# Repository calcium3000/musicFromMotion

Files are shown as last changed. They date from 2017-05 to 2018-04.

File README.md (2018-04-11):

# musicFromMotion
Convert your slick grooves into sweet tunes.  Body movements are transmitted wirelessly to a host computer and then translated into pre-programmed beats and instruments.  And everything is reconfigurable on the fly; you can serenade or offend the airwaves however you please.

See https://calcium3000.wordpress.com/projects/mfm for more information on the project.

## Hardware
### mFM-Rx
This is the receiver module with which all transmitter nodes communicate.  It consists of a small breakout board for a mini nRF24L01+ transceiver module that plugs directly into the SPI0 bus of a Raspberry Pi (all models).

This module is used in conjunction with TMRh20's RF24 library (see https://github.com/TMRh20/RF24).

### mFM-Tx
Behold the transmitter modules -- the lustrous face of mFM.  Each module consists of a battery, a voltage regulator, a radio transceiver, an accelerometer, and a microcontroller.

When the Rx node pings a Tx node, it reads it accelerometer value and battery status (good or low), sends it back to the Rx node, and takes a quick nap while the other nodes are being pinged.  If the battery voltage is too low the module will sleep until the battery is recharged.

**Note: this version is currently in progress and untested.  Use at your own risk!  And if you do and have any comments or suggestions, please share!**

### License
mFM hardware is licensed under the TAPR Open Hardware License.  See http://tapr.org/ohl.html or LICENSE.txt for full details of the license agreement.

## Software
This section is currently under construction -- i.e. I need to get everything pretty enough to share on the interwebs.  But behold the list of eventual components:
- Tx firmware (Arduino)
- Rx program (C++)
- Rx UDP configurator GUI (optional, Python)
- Main audio program (Pure Data)

### License
All software is licensed under the GNU Public License (GPL) version 3.  See https://www.gnu.org/licenses or COPYING.txt for full details of the license agreement.

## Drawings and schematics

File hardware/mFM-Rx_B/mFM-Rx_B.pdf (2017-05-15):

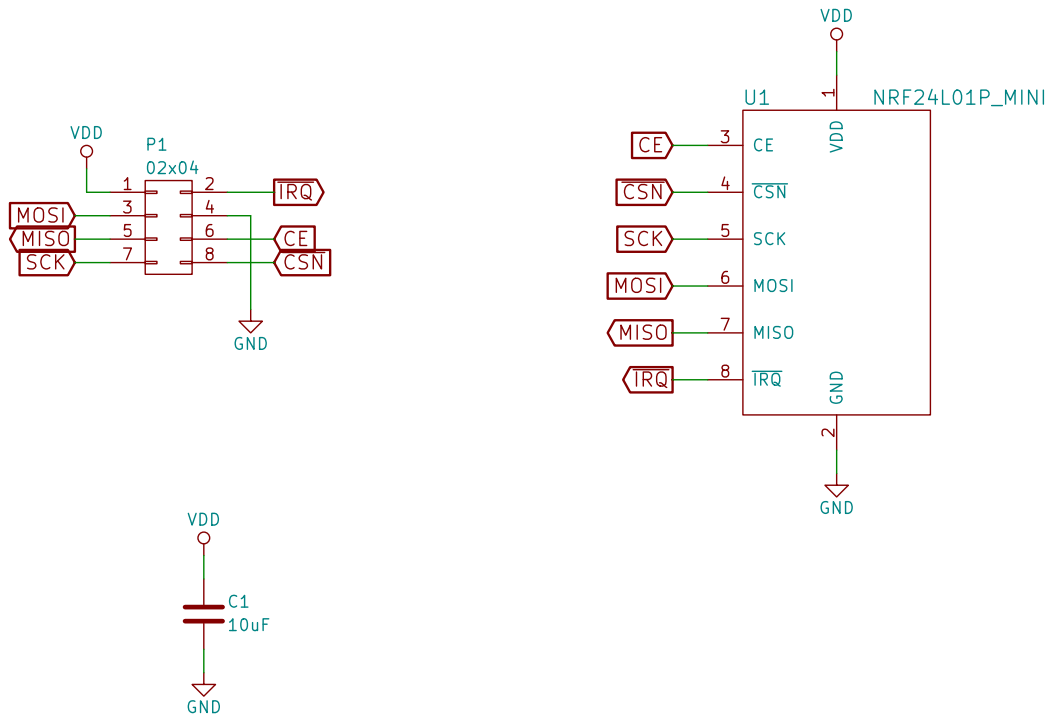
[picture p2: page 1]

1 GND
Released under the TAPR Open Hardware License >> http://tapr.org/ohl.html VDD

2 CE 3 CSN 4 SCK 5 MOSI 6 MISO 7

File: mFM-Rx_B.sch Sheet: / By Calvin A. Cherry >> calvincherry@gmail.com

Id: 1/1 Title: musicFromMotion Receiver (Rx)

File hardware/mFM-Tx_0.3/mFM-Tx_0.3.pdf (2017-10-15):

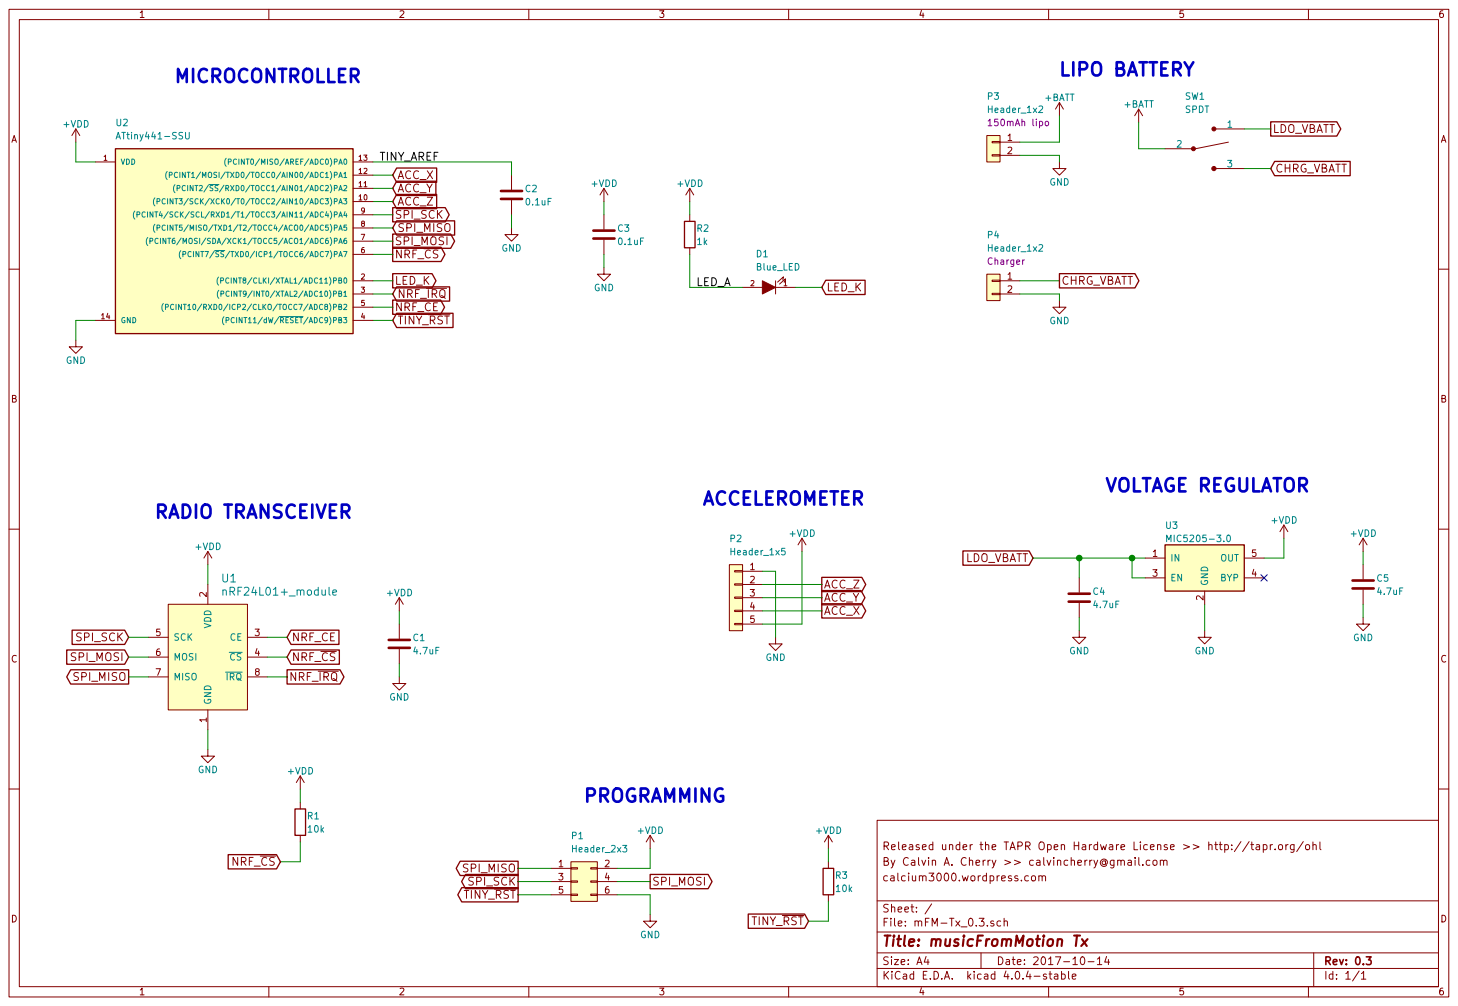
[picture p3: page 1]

Released under the TAPR Open Hardware License >> http://tapr.org/ohl 1

2 CE 3 CS 4 SCK 5 MOSI 6 MISO 7

By Calvin A. Cherry >> calvincherry@gmail.com
File: mFM-Tx_0.3.sch Sheet: / calcium3000.wordpress.com

Id: 1/1 Title: musicFromMotion Tx

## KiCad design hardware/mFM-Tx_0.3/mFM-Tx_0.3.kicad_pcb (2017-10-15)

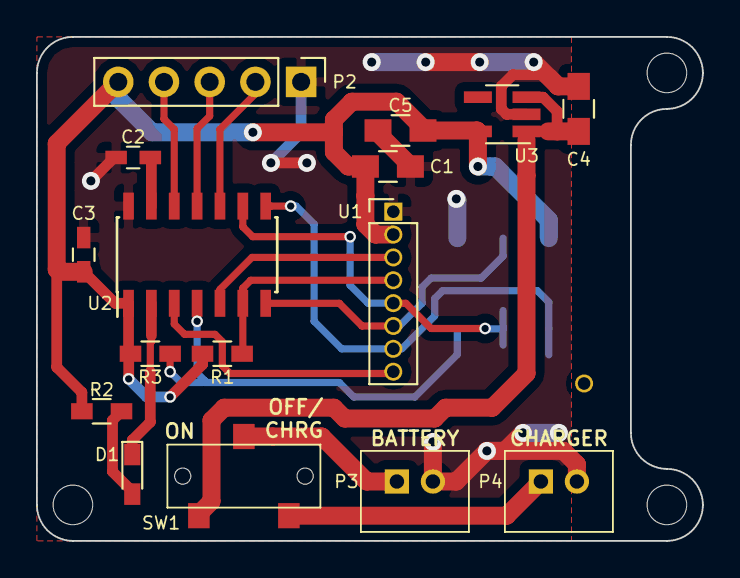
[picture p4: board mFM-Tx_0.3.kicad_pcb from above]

Board: 2 copper layers, 37.0 x 28.0 mm, 20 parts (1 on the bottom side), 18 nets.

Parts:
C1, C4, C5: 4.7uF; C_0805_HandSoldering
C2, C3: 0.1uF; C_0603_HandSoldering
D1: Blue_LED; LED_0603_HandSoldering
MH0, MH1, MH2: MountingHole_2.2mm_M2_ISO7380
P1: Header_2x3; Socket_Strip_Straight_2x03_Pitch2.54mm_SMD
P2: Header_1x5; ADXL335_header
P3, P4: Header_1x2; B2B-PH-K-S
R1, R3: 10k; R_0603_HandSoldering
R2: 1k; R_0603_HandSoldering
SW1: SPDT; CL-SB-12B-11T
U1: nRF24L01+_module; nRF24L01p_mini_header
U2: ATtiny441-SSU; SOIC-14_3.9x8.7mm_Pitch1.27mm
U3: MIC5205-3.0; SOT-23-5_HandSoldering

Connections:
+BATT: P3.1, SW1.2
+VDD: C1.1, C3.1, C5.1, P1.2, P2.5, R1.1, R2.1, R3.1, U1.2, U2.1, U3.5
/LED_A: D1.2, R2.2
/TINY_AREF: C2.1, U2.13
ACC_X: P2.4, U2.12
ACC_Y: P2.3, U2.11
ACC_Z: P2.2, U2.10
CHRG_VBATT: P4.1, SW1.3
GND: C1.2, C2.2, C3.2, C4.2, C5.2, P1.6, P2.1, P3.2, P4.2, U1.1, U2.14, U3.2
LDO_VBATT: C4.1, SW1.1, U3.1, U3.3
LED_K: D1.1, U2.2
NRF_CE: U1.3, U2.5
NRF_~CS~: R1.2, U1.4, U2.6
NRF_~IRQ~: U1.8, U2.3
SPI_MISO: P1.1, U1.7, U2.8
SPI_MOSI: P1.4, U1.6, U2.7
SPI_SCK: P1.3, U1.5, U2.9
TINY_~RST~: P1.5, R3.2, U2.4

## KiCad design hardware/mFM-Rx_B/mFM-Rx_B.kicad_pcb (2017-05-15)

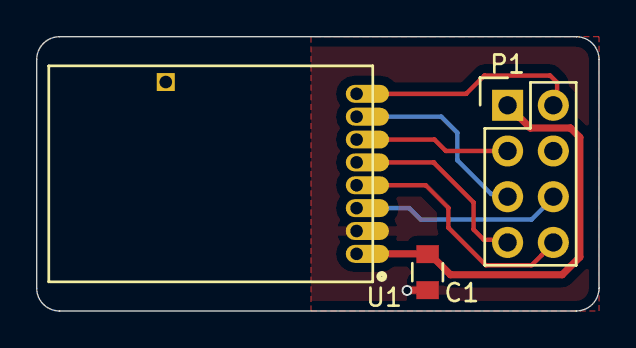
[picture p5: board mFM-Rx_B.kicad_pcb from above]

Board: 2 copper layers, 31.2 x 15.2 mm, 3 parts (0 on the bottom side), 8 nets.

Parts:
C1: 10uF; C_0805
P1: 02x04; Socket_Strip_Straight_2x04_mirrored
U1: NRF24L01P_MINI; nRF24L01p_mini_TH

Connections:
CE: P1.6, U1.3
GND: C1.2, P1.4, U1.2
MISO: P1.5, U1.7
MOSI: P1.3, U1.6
SCK: P1.7, U1.5
VDD: C1.1, P1.1, U1.1
~CSN: P1.8, U1.4
~IRQ: P1.2, U1.8

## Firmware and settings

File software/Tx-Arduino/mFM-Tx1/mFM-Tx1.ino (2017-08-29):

/*
 * mFM-Tx1.ino
 * 
 * Copyright 2017  Calvin A. Cherry (calvincherry@gmail.com)
 *                 calcium3000.wordpress.com
 * 
 * RF24 library courtesy of TMRh20.
 * http://tmrh20.github.io/RF24
 * 
 * LowPower library courtesy of RocketScream.
 * https://github.com/rocketscream/Low-Powerdfx
 * 
 * Secret Arduino voltmeter provided by Provide Your Own
 * https://provideyourown.com/2012/secret-arduino-voltmeter-measure-battery-voltage
 * 
 * Use:
 *   This Tx controller was built around an Arduino Pro Mini 3.3V.  An ADXL335
 *   3-axis accelerometer module -- 5-pin version, with ST pin next to the IC -- 
 *   serves as the motion sensor, while a mini nRF24L01+ transceiver module
 *   communicates with the Rx on a Raspberry Pi.  Both the accelerometer and
 *   transceiver (radio) are attached in a mezzanine fashion atop the Arduino
 *   with the pinouts as such:
 *
 *   Arduino | ADXL335
 *   --------+--------
 *   VCC     | VCC
 *   A3      | X_OUT
 *   A2      | Y_OUT
 *   A1      | Z_OUT
 *   A0*     | GND
 *   
 *   Arduino | nRF24L01+
 *   --------+----------
 *   VCC**   | +3.3V
 *   D6*     | GND
 *   D9      | CE
 *   D8      | CSN
 *   D13     | SCK
 *   D11     | MOSI
 *   D12     | MISO
 *   NC      | IRQ
 * 
 *   *Pin is set to output low in software to act as a ground.
 *   **Soldered to same VCC pin as the ADXL335.
 *   
 *   An LIR2450 coin cell battery and inline SPST switch are connected to
 *   the RAW and GND pins of the Arduino.  Also, a 5-pin female header is
 *   connected to the GRN, TX, RX, VCC, and GND pins for programming.
 *   
 *   A few items must also be removed: the power LED indicator, the LED
 *   connected to pin 13 (SCK), and the reset button.  For the LEDs, it
 *   suffices to remove the inline resistors instead.
 * 
 * 
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
 * You should have received a copy of the GNU General Public License
 * along with this program; if not, write to the Free Software
 * Foundation, Inc., 51 Franklin Street, Fifth Floor, Boston,
 * MA 02110-1301, USA.
 */

#include <SPI.h>
#include <LowPower.h>
#include <RF24.h>

#define ACTING_GROUND_1     A0
#define ACTING_GROUND_2     6
#define ANALOG_X            A3
#define ANALOG_Y            A2
#define ANALOG_Z            A1
#define CE_PIN              9
#define CSN_PIN             8


/* * * * * * * * * * * * * * * * * * * * * * * * * * * * * * * * * * * *
 * CONSTANTS
 * * * * * * * * * * * * * * * * * * * * * * * * * * * * * * * * * * */
const uint8_t THIS_NODE_NUMBER = 1;

const uint64_t PIPES[5] = {0xc0dca1150ALL,
                           0xc0dca1151BLL,
                           0xc0dca1152CLL,
                           0xc0dca1153DLL,
                           0xc0dca1154ELL};

const float ADC_CORRECTION_FACTOR = 2.968 / 2.85609;
const float V_BATTERY_LOW = 2.9;
const float V_BATTERY_SHUTDOWN = 2.8;


/* * * * * * * * * * * * * * * * * * * * * * * * * * * * * * * * * * * *
 * VARIABLES
 * * * * * * * * * * * * * * * * * * * * * * * * * * * * * * * * * * */
boolean low_battery_shutdown = false;

byte measure_battery_counter = 0;
byte received_byte = 0;

struct payload {
  byte node_number = 250 + THIS_NODE_NUMBER;
  byte value_x = 0;
  byte value_y = 0;
  byte value_z = 0;
  byte battery_status = 1;
} tx_accelerometer_values;

RF24 radio(CE_PIN, CSN_PIN);


/* * * * * * * * * * * * * * * * * * * * * * * * * * * * * * * * * * * *
 * FUNCTIONS
 * * * * * * * * * * * * * * * * * * * * * * * * * * * * * * * * * * */
 // Setup radio, acting grounds, and accelerometer inputs
void setup(void)
{
  radio.begin();
  
  radio.setDataRate(RF24_1MBPS);
  radio.setPALevel(RF24_PA_LOW);
  
  radio.openWritingPipe(PIPES[THIS_NODE_NUMBER]);
  radio.openReadingPipe(1, PIPES[0]);
  radio.startListening();
  
  pinMode(ACTING_GROUND_1, OUTPUT);
  pinMode(ACTING_GROUND_2, OUTPUT);
  digitalWrite(ACTING_GROUND_1, LOW);
  digitalWrite(ACTING_GROUND_2, LOW);
  
  pinMode(ANALOG_X, INPUT);
  pinMode(ANALOG_Y, INPUT);
  pinMode(ANALOG_Z, INPUT);
} // setup()


// Main loop
void loop(void)
{
  // If any data is received
  if (radio.available())
  {
    while(radio.available())
    {
      // Read node number from Rx
      radio.read(&received_byte, 1);
    }
    
    if (received_byte == tx_accelerometer_values.node_number)
    {
      // Read accelerometer values and transmit
      radio.stopListening();
      get_tx_accelerometer_values();
      radio.write(&tx_accelerometer_values, sizeof(tx_accelerometer_values));
      
      // Sleep for 15ms
      radio.powerDown();
      LowPower.idle(SLEEP_15MS, ADC_OFF, TIMER2_OFF, TIMER1_OFF,
                    TIMER0_OFF, SPI_OFF, USART0_OFF, TWI_OFF);
      radio.powerUp();
      radio.startListening();
    }
  }
  
  if (low_battery_shutdown)
  {
    power_down_mode();
  }
  
  // Measure battery voltage every 256 cycles (about every 5 seconds)
  if (measure_battery_counter == 0)
  {
    measure_battery_voltage();
  }
  measure_battery_counter += 1;
} // loop()


// Read accelerometer values from analog pins
void get_tx_accelerometer_values(void)
{
  tx_accelerometer_values.value_x = map(analogRead(ANALOG_X),0,1023,0,127);
  tx_accelerometer_values.value_y = map(analogRead(ANALOG_Y),0,1023,0,127);
  tx_accelerometer_values.value_z = map(analogRead(ANALOG_Z),0,1023,0,127);
} // get_tx_accelerometer_values()


// Measure battery voltage and set battery status variable
void measure_battery_voltage(void)
{
  float current_vdd = read_vdd() * ADC_CORRECTION_FACTOR;

  if(current_vdd >= V_BATTERY_LOW)
  {
    tx_accelerometer_values.battery_status = 1;
    low_battery_shutdown = false;
  }
  else if(current_vdd >= V_BATTERY_SHUTDOWN)
  {
    tx_accelerometer_values.battery_status = 0;
    low_battery_shutdown = false;
  }
  else
  {
    tx_accelerometer_values.battery_status = 0;
    low_battery_shutdown = true;
  }
} // measure_battery_voltage()


// Use 'secret voltmeter' to measure battery voltage
float read_vdd(void)
{
  ADMUX = _BV(REFS0) | _BV(MUX3) | _BV(MUX2) | _BV(MUX1);
  
  delay(3);
  ADCSRA |= _BV(ADSC);
  while (bit_is_set(ADCSRA, ADSC));
  
  uint8_t low_byte  = ADCL;
  uint8_t high_byte = ADCH;
  
  float result = (high_byte << 8) | low_byte;
  
  result = 1125.3 / result;
  return result;
} // read_vdd()


// Power down Tx and check battery voltage every 8 seconds until ample battery
//   voltage is restored
void power_down_mode(void)
{
  radio.powerDown();
  
  while(low_battery_shutdown)
  {
    LowPower.powerDown(SLEEP_8S, ADC_ON, BOD_OFF);
    measure_battery_voltage();
  }
  
  radio.powerUp();
  radio.startListening();
} // power_down_mode()

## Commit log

2016-07-23 Initial commit of Rx, Tx, and pretty
    [mFM-Rx-B.Cu.gbl, mFM-Rx-B.Mask.gbs, mFM-Rx-B.SilkS.gbo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]
2016-07-29 Updated schematics and PCBs
    [mFM-Rx.sch, mFM-Tx.kicad_pcb, mFM-Tx.sch]
2016-07-29 Updated Tx PCB
2016-07-30 Created Tx gerbers
    [mFM-Tx-B.Cu.gbl, mFM-Tx-B.Mask.gbs, mFM-Tx-B.SilkS.gbo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]
2017-05-15 Updated component and footprint libraries, updated mFM-Tx to Rev C, updated mFM-Rx to Rev B
    [mFM-Rx-B.Cu.gbl, mFM-Rx-B.Mask.gbs, mFM-Rx-B.SilkS.gbo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]
2017-08-28 Created separate folders for hardware and software files
    [mFM-Rx_B-B.Cu.gbl, mFM-Rx_B-B.Mask.gbs, mFM-Rx_B-B.SilkS.gbo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]
2017-08-28 Added Tx Arduino sketch for node 1 (left hand)
2017-08-28 Updated 'Use' section for Tx1 Arduino sketch
2017-08-29 Added Rx files, moved logo, updated Tx Arduino sketch
2017-09-28 Added Tx hardware files for versions 0.1 and 0.2
    [mFM-Tx_0.1.kicad_pcb, mFM-Tx_0.1.sch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]
2017-09-28 Updated gerbers for Tx_0.1 and _0.2
    [mFM-Tx_0.1.kicad_pcb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]
2017-09-30 Updated VDD to 3.3V on mFM-Tx_0.2
    [mFM-Tx_0.1-B.Cu.gbl, mFM-Tx_0.1-B.Mask.gbs, mFM-Tx_0.1-B.SilkS.gbo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]
2017-10-15 Upgraded to Tx 0.3, substituted ATtiny441 for ATmega328p, removed serial programming, modified PCB layout
    [mFM-Tx_0.2-B.Cu.gbl, mFM-Tx_0.2-B.Mask.gbs, mFM-Tx_0.2-B.SilkS.gbo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]

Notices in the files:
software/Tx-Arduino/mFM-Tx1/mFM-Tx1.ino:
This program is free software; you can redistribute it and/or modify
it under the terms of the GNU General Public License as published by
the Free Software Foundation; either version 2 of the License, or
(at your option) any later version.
